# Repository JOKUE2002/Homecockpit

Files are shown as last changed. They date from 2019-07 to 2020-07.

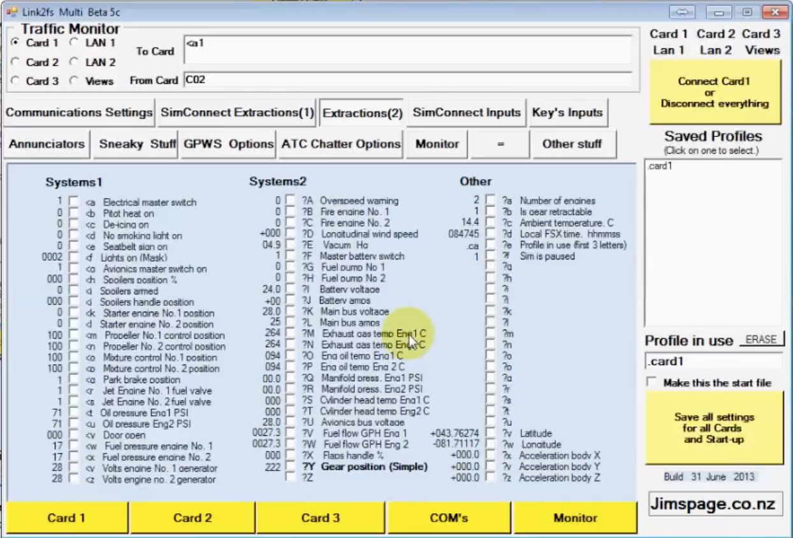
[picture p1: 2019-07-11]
hardware/simconnect-extractions2.png

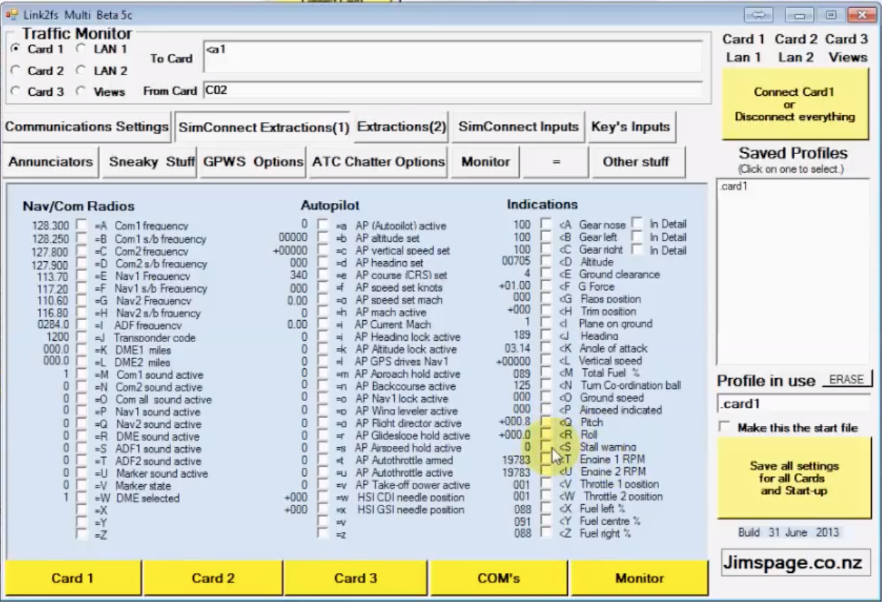
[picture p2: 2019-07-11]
hardware/simconnect-extractions1.png

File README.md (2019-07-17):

# Homecockpit

## What is it?
The homecockpit is a piece of hardware, that emulates a cockpit for a given computergame.
In this case we're emulating a "universal" cockpit in M$ FSX:SE.
"Universal" means, that it is adapted, so that it can be used on any aircraft type.

## What is the main concept?
The main concept is to have a big frame with cutouts, where panels are _slotted_. 
The frame features:
* space for 7 panels (6x 20x10cm + 1x 10x20cm), 
* a cutout for a monitor to show more complex instruments (PFD, GPS, ...)
* a cutout to fit the saitek yoke
* a powerbar
* an Arduino MEGA as the "brain"

## Which panels are already finished?
* Basic LightsPanel
  * bunch of simple two-state-switches to control lights in and around the aircraft
  * hardware nearly done ( First set of switches done, needs integration with Sim-commands panel)
  * software 0%
* Basic RadioPanel
  * 2 frequency displays + 1 knob (to set s/b freqency)
  * Hardware done (100%)
  * Software still WIP (w/ main firmare)
* AutopilotPanel Part 1
  * CRS, HDG, SPD displays + knobs
  * hardware done (100%)
  * software still WIP (w/ main firmare), but a beta has already been written and tested
* AutopilotPanel Part 2
  * ALT, V/S displays + knobs
  * hardware done (100%)
  * same software as AutopilotPanel Part 1
* Advanced RadioPanel
  * SQUAWK display + setting buttons; com/nav selector/switch buttons
  * hardware work in progress (50% done)
  * software not yet started, but easy (0%)
* Landing gear lever
  * lever with pull function to lock it into three positions (UP, LK, DN)
  * hardware WIP (lever done , installation + wiring missing)
  * software 0%
  
## Which panels are still planned?
* Sim-commands panel
  * buttons to command fsx (pause, slew mode, kneeboard, ...)
* Electrical panel
  * Hydraulics, APU, Generators, ...
* Engine Panel
  * Engine starters, fire suppresion, ...

## What's included?
In the "_pcb_" folder, there are the EAGLE **.sch**ematic/**.b**oa**rd** files for the custom PCBs we designed and ordered to make things easier.
In the "_firmware_" folder there are nearly all iterations of the firmaware, including the current version ("_FSX_3.0_").
In the "_parts_" folder there is a list of all the parts, that have been used to build the cockpit.

## How much is done is it?
If we had to guess this would be like one third done. There are still ~~a few~~ a lot of the planned panels missing. Also the main frame is still a work in progress.

### Individual statuses
* Frame: 70%
* Firmware: 40%
* Panels: 40%
* whole project: 30%

## Who's contributing?
Currently there are two main contributers:
Jonas (Hardware & Software specialist)
Cornelius (Flightsim/flying & design specialist)

## How can you contact us / help us?
Just create an issue. We'll answer on it as soon as possible.

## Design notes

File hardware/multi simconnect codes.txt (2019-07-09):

Send these codes from your Arduino with a 'Serial.println'
(The data burst needs to end with a linefeed)
There is nothing else for you to do. It will go to FSX automatically.
Some of these may not work on some planes. (Test them to check they work)

Simconnect direct injection codes.

Below are the codes you would send from the Arduino to do the required command.
You only need to send it once.
Make sure they are sent with "Serial.println(code)" command.
Note the println ,, as this sends the required linefeed after the code.

Examples ,,,
To raise the gear ,,,
Serial.println("C01");

To lower the gear ,,
Serial.println("C02");

To turn the autopilot on ,,
Serial.println("B03");

To set the transponder to 3254 ,,
Serial.println("A423254");

Make sure it's a capital letter.
This has nothing to do with the "Keys" section.
Just send the code from the Arduino and it will happen.
Easy, isn't it.?????

---- RADIO's  Codes --------------------------------------------------

A01	Decrements COM by one MHz
A02	Increments COM by one MHz
A03	Decrements COM by 25 KHz
A04	Increments COM by 25 KHz
A05xxxx	Sets COM frequency (In Hz) (A05 and 4 digits, the '1' is assumed, no dot)
A06	Swaps COM 1 frequency with standby
A07	Decrements COM2 by one MHz
A08	Increments COM2 by one MHz
A09	Decrements COM2 by 25 KHz
A10	Increments COM2 by 25 KHz
A11xxxx	Sets COM2 frequency(In Hz) (A11 and 4 digits, the '1' is assumed, no dot)
A12	Swaps COM 2 frequency with standby
A13	Decrements Nav 1 by one MHz
A14	Increments Nav 1 by one MHz
A15	Decrements Nav 1 by 25 KHz
A16	Increments Nav 1 by 25 KHz
A17xxxx	Sets NAV 1 frequency (In Hz) (A17 and 4 digits, the '1' is assumed, no dot)
A18	Swaps NAV 1 frequency with standby
A19	Decrements Nav 2 by one MHz
A20	Increments Nav 2 by one MHz
A21	Decrements Nav 2 by 25 KHz
A22	Increments Nav 2 by 25 KHz
A23xxxx	Sets NAV 2 frequency (In Hz) (A23 and 4 digits, the '1' is assumed, no dot)
A24	Swaps NAV 2 frequency with standby
A25	Increments ADF by 100 KHz
A26	Increments ADF by 10 KHz
A27	Increments ADF by 1 KHz
A28	Increments ADF 1 by 0.1 KHz.
A29	Decrements ADF by 100 KHz
A30	Decrements ADF by 10 KHz
A31	Decrements ADF by 1 KHz
A32	Decrements ADF 1 by 0.1 KHz.
A33xxxxx   Sets ADF 1 frequency (In Hz)  (A33 and 5 digits, no dot)
A34	Increments first digit of transponder
A35	Increments second digit of transponder
A36	Increments third digit of transponder
A37	Increments fourth digit of transponder
A38	Decrements first digit of transponder
A39	Decrements second digit of transponder
A40	Decrements third digit of transponder
A41	Decrements fourth digit of transponder
A42xxxx	Sets transponder code (A42 + 4 digits)
A43x	Sets the avionics master switch (0,1) A431 is on, A430 is off
A44	Toggles between NAV 1 and NAV 2
A45	Selects COM 1 to transmit
A46	Selects COM 2 to transmit
A47	Toggles all COM radios to receive on
A48	Toggles NAV 1 ID
A49	Toggles NAV 2 ID
A50	Toggles DME 1 ID
A51	Toggles DME 2 ID
A52	Toggles ADF 1 ID
A53	Toggles marker beacon sound on/off
A60x          DME select (A601 is DME1, A602 is DME2)

--- AUTOPILOT  Codes -----------------------------------------------------

A54	Toggles between GPS and NAV 1 driving NAV 1 OBS display (and AP)
A55	Decrements VOR 1's OBS setting (Course)
A56	Increments VOR 1's OBS setting  (Course)
A57	Increments heading hold reference bug
A58	Decrements heading hold reference
A59xxx	Set heading hold reference bug (degrees) (A59 and 1 to 3 digits)
B01	Toggles AP on/off
B02	Turns AP off
B03	Turns AP on
B04	Toggles heading hold mode
B05	Toggles altitude hold mode
B06	Toggles wing leveler mode
B07	Turns AP localizer hold on/armed and glide-slope hold mode off
B08	Toggle, Turns both AP localizer and glide-slope modes on/armed
B09	Toggles the backcourse mode for the localizer hold
B10	Toggles the nav hold mode
B11	Increments reference altitude
B12	Decrements reference altitude
B13	Increments vertical speed reference
B14	Decrements vertical speed reference
B15	Increments airspeed hold reference
B16	Decrements airspeed hold reference
B17	
B18	Increments reference mach
B19	Decrements reference mach
B20	Toggles mach hold
B21xxxx	Sets reference vertical speed in feet per minute (B21 & 3 or 4 digits)
B22xxx	Sets airspeed reference in knots (B22 and 1 to 3 digits)
B23xxx	Sets mach reference (B23 and 1 to 3 digits,  no dot)
B24	Turns airspeed hold on
B25	Turns airspeed hold off
B26           Toggle airspeed hold
B26x	Sets airspeed hold on/off (1,0)  (B261is on, B260 is off)
B27	Turns mach hold on
B28	Turns mach hold off
B29x	Sets mach hold on/off (1,0)  (B291is on, B290 is off)
B30	Toggles flight director on/off
B30x         Sets flight director on/off  (B301 is on, B300 is off)
B31	Toggle N1 hold
B32xxxxx  Sets altitude reference in feet  (B32 with 3 to 5 digits)
B33xxx      Sets OBS 1 (0 – 360)  (B32 with 1 to 3 digits)
B34           Toggle Autothrottle armed
B34x         Set autothrottle armed on/off  (B341 is on, B340 is off)
B35           Syncs altimeter setting to sea level pressure, or 29.92 if above 18000 feet 

--- OTHER  Codes------------------------------------------------------

C01	Sets gear handle in UP position
C02	Sets gear handle in DOWN
C03	Toggle gear handle
C04	Toggle parking brake on/off
C04x         Parking brake on/off (C041 is ON, C040 is off)
C05	Turns pitot heat switch on
C06	Turns pitot heat switch off
C07	Adds fuel to the aircraft, 25% of capacity at a time.
C08	Toggles pause on/off
C09	Turns on or off the fuel dump switch.
C10	Release one droppable object. Multiple key events will release multiple objects.
C11	Start up the auxiliary power unit (APU).(See E30)
C12	Extinguish all engine fires.
C13	Sets flap handle to full retract position
C14	Increments flap handle position
C15	Decrements flap handle position
C16	Sets flap handle to full extension position
C17xxx	Sets flap handle to closest increment (0 – 100%) (C17 with 1 to 3 digits)
C18	Increment elevator trim up
C19	Increments elevator trim down
C20	Sets auto-spoiler arming on
C21	Spoilers off
C22	Toggles spoiler handle
C23	Sets spoiler handle to full extend position
C24	Sets spoiler handle to full retract position
C25          Increase Kohlsman reading (Altimeter)
C26          Decrease Kohlsman reading (Altimeter)
C27          Increments rudder trim left
C28          Increments rudder trim right 
C29          Toggle "Push back" on/off
C30xxx    Cowl flap 1 set (0 – 100%) (C30 and 1 to 3 digits) 
C31xxx    Cowl flap 2 set (0 – 100%) (C30 and 1 to 3 digits) 
C32          Floats down (depends on plane if it works)
C33          Floats up (depends on plane if it works)
C34          Toggle smoke
C35          Smoke On
C36          Smoke Off
C37          Toggle wing folding
C38          Toggle tail hook handle
C39          Toggle water rudder

---  LIGHTS  Codes ---------------------------------------------

C41x       Nav lights   (C411 is On, C410 is Off)
C42x       Beacon lights   (C421 is On, C420 is Off)
C43x       Landing lights   (C431 is On, C430 is Off)
C44x       Taxi lights   (C441 is On, C440 is Off) 
C45x       Strobe lights   (C451 is On, C450 is Off)
C46x       Panel lights   (C461 is On, C460 is Off)
C47x       Recognition lights   (C471 is On, C470 is Off)
C48x       Wing lights   (C481 is On, C480 is Off) 
C49x       Logo lights   (C491 is On, C490 is Off) 
C50x       Cabin lights   (C501 is On, C500 is Off) 

---  ELECTRICAL  Codes  ----------------------------

A43x        Sets the avionics master switch (0,1) A431 is on, A430 is off
E01          Set engine 1 magnetos off 
E02          Toggle engine 1 right magneto
E03          Toggle engine 1 left magneto
E04          Set engine 1 magnetos on 
E05          Set engine 1 magnetos on and toggle starter
E06          Set engine 2 magnetos off
E07          Toggle engine 2 right magneto 
E08          Toggle engine 2 left magneto
E09          Set engine 2 magnetos on 
E10          Set engine 2 magnetos on and toggle starter 
E11          Set engine magnetos off
E12          Set engine right magnetos on
E13          Set engine left magnetos on 
E14          Set engine magnetos on 
E15          Set engine magnetos on and toggle starters (all)
E16          Toggle master battery switch
E17          Master battery switch OFF
E18          Master battery switch ON
E19          No.1  Alternator (generator) Toggle
E20          No.1  Alternator (generator) OFF
E21          No.1  Alternator (generator) ON
E22          No.2  Alternator (generator) Toggle
E23          No.2  Alternator (generator) OFF
E24          No.2  Alternator (generator) ON
E25          Toggle master alternator on/off
E26          Toggle master ignition switch  on/off
E27          Hydraulic pump switch 1    (E27 is toggle, E271 is On, E270 is Off)
E28          Hydraulic pump switch 2    (E28 is toggle, E281 is On, E280 is Off)
E29          Hydraulic pump switch 3    (E29 is toggle, E291 is On, E290 is Off)
C11         APU start 
E30          APU stop
E31          APU generator On
E32          APU generator Off
E33          Prop syncro switch   (E33 is toggle, E331 is on, E330 is off)
E34          Toggle all starters
E35          Triggers engine auto start
E36          Triggers engine auto shut down
E37          Triggers engine primer
E38          Toggle master ignitian switch
E39          Toggle master battery and alternator switch
E40          
E41          Toggle starter 1
E42          Starter 1  On
E43          Starter 1  Off
E44         Toggle starter 2
E45         Starter 2 On
E46         Starter 2 Off

--- FUEL  Systems  ---------------------------------------------

F01       Toggle fuels pumps on/off
F02x     Engine 1 fuel pump. (F021 is On, F020 is Off)
F03x     Engine 2 fuel pump. (F031 is On, F030 is Off)
F04x     Sets fuel selector 1 position (F04 and 1 or 2 digits ) (see list below)
F05x     Sets fuel selector 2 position (F05 and 1 or 2 digits ) (see list below)
		0 = Off
		1 = All
		2 = Left
		3 = Right
		4 = Left Aux
		5 = Right Aux
		6 = Center
		7 = Center2
		8 = Center3
		9 = External1
		10 = External2
		11 = Right tip
		12 = Left tip
		13 = Crossfeed
		14 = Crossfeed left to right
		15 = Crossfeed right to left
		16 = Both
		17 = External all
		18 = Isolate
F06        Crossfeed  On
F07        Crossfeed Off
F08        Add some fuel to total volume
F09        Turns on or off the fuel dump switch
F30        Toggle engine fuel valves
F31        Toggle engine 1 fuel valve
F32        Engine 1 fuel valve On
F33        Engine 1 fuel valve Off
F34        Toggle engine 2 fuel valve
F35        Engine 2 fuel valve On
F36        Engine 2 fuel valve Off

--- ANTI - ICE  Codes  --------------------------------------

F10        Anti ice On  
F11        Anti ice Off 
F12        Anti ice Toggle  
F13        Engine1 anti ice Off
F14        Engine1 anti ice On
F15        Engine2 anti ice Off
F16        Engine2 anti ice On
F17        Toggle structural de-ice
F18        Toggles propeller de-ice

---  HELICOPTERS  --------  Not tested, Maybe r22 only  ---------------

F19        Triggers rotor braking input
F20        Toggles on electric rotor clutch switch
F21        Sets electric rotor clutch switch On 
F22        Sets electric rotor clutch switch Off 
F23        Toggles the electric rotor governor switch
F24        Sets the electric rotor governor switch On
F25        Sets the electric rotor governor switch Off
F26        Increments the lateral (right) rotor trim
F27        Decrements the lateral (right) rotor trim

As mentioned above, some of these may not work on some planes.
Don't blame me ,, some planes are not set up 100% for simconnect ,,,
even M$ with the Baron ,, the de-ice wont work ,,
so TEST  THEM  FIRST before coding the Arduino for a particular planes function.

Also note ,,,
Some knobs or switches that appear to not work, actually may be working because 
the developer has not added the code to change the visual switch that you see.
Also if "X" wont work ,,, check that "Y" (and maybe "Z") is in the 'on' (or off) 
position first as some simconnect commands do away with the automatic 
'systems' stuff that happens for the casual user.

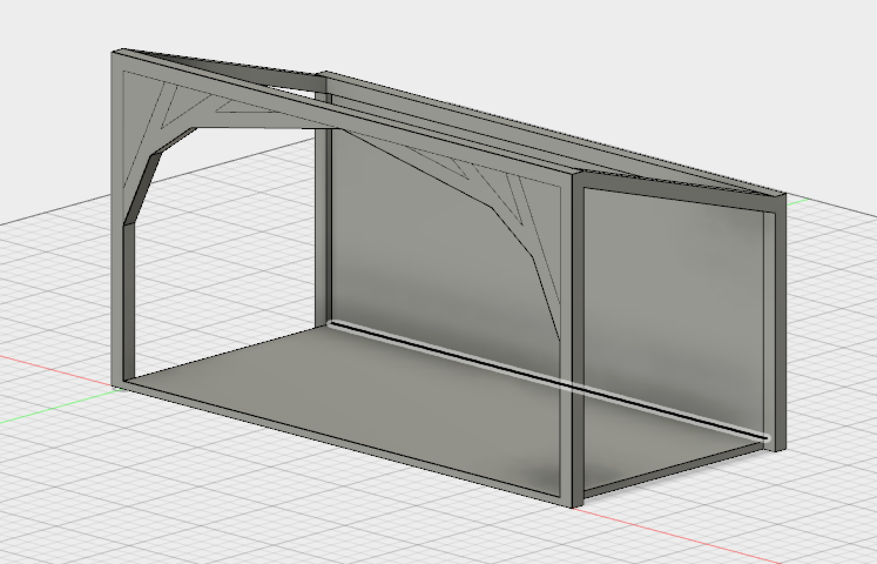
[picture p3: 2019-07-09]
hardware/Screenshot_1.png

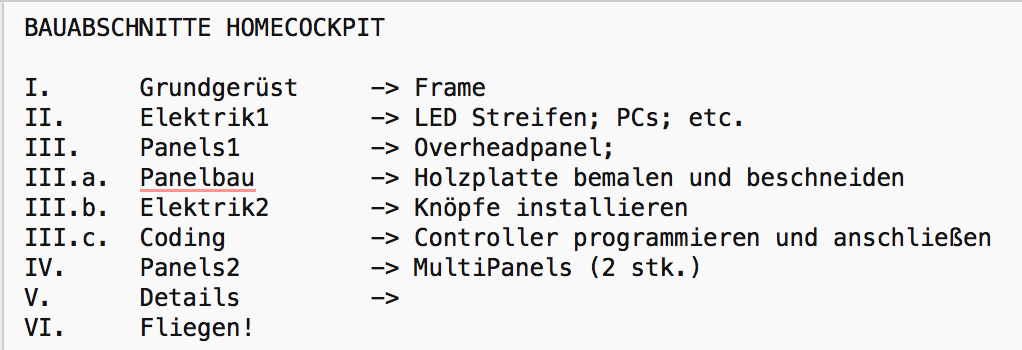
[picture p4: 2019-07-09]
hardware/Screenshot_4.png

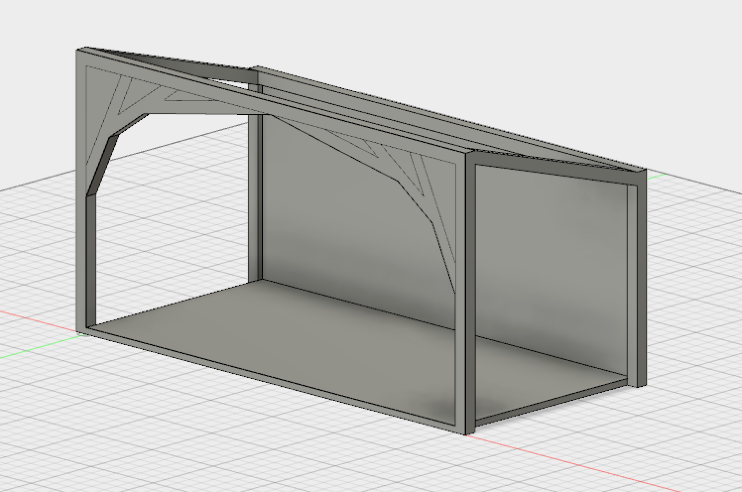
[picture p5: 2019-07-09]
hardware/Screenshot_2.png

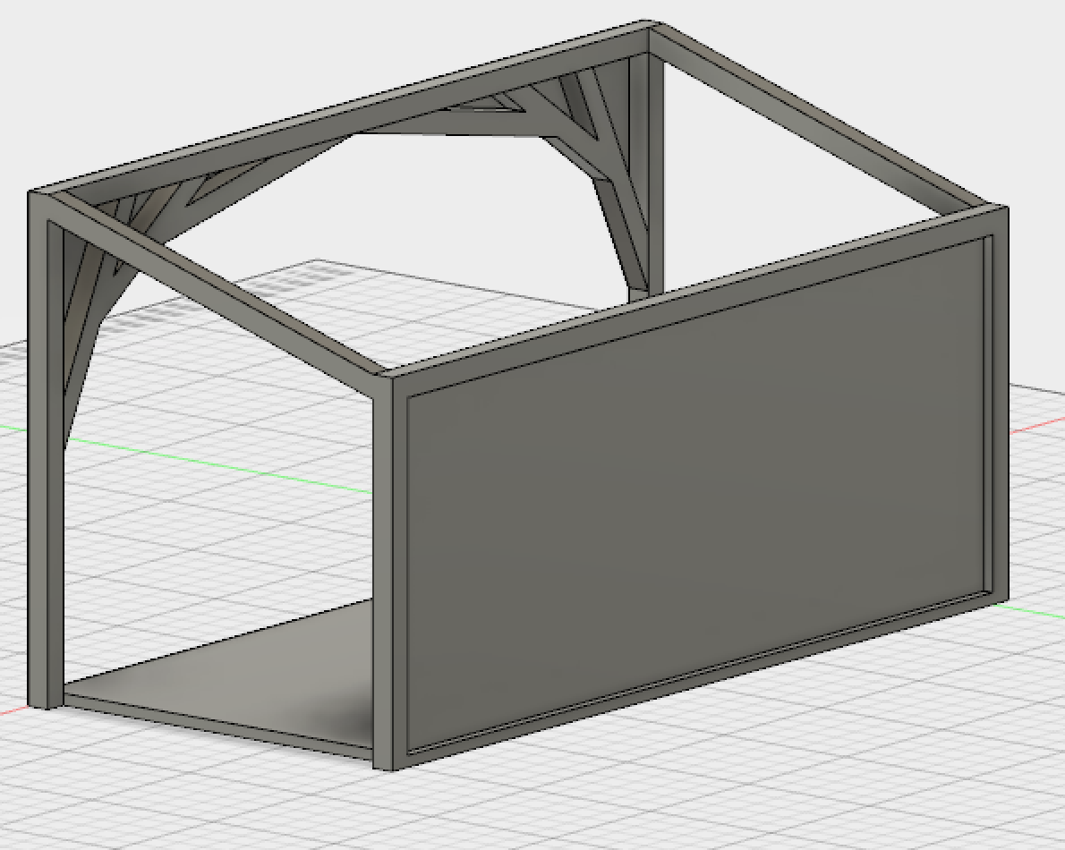
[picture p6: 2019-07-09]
hardware/Screenshot_3.png

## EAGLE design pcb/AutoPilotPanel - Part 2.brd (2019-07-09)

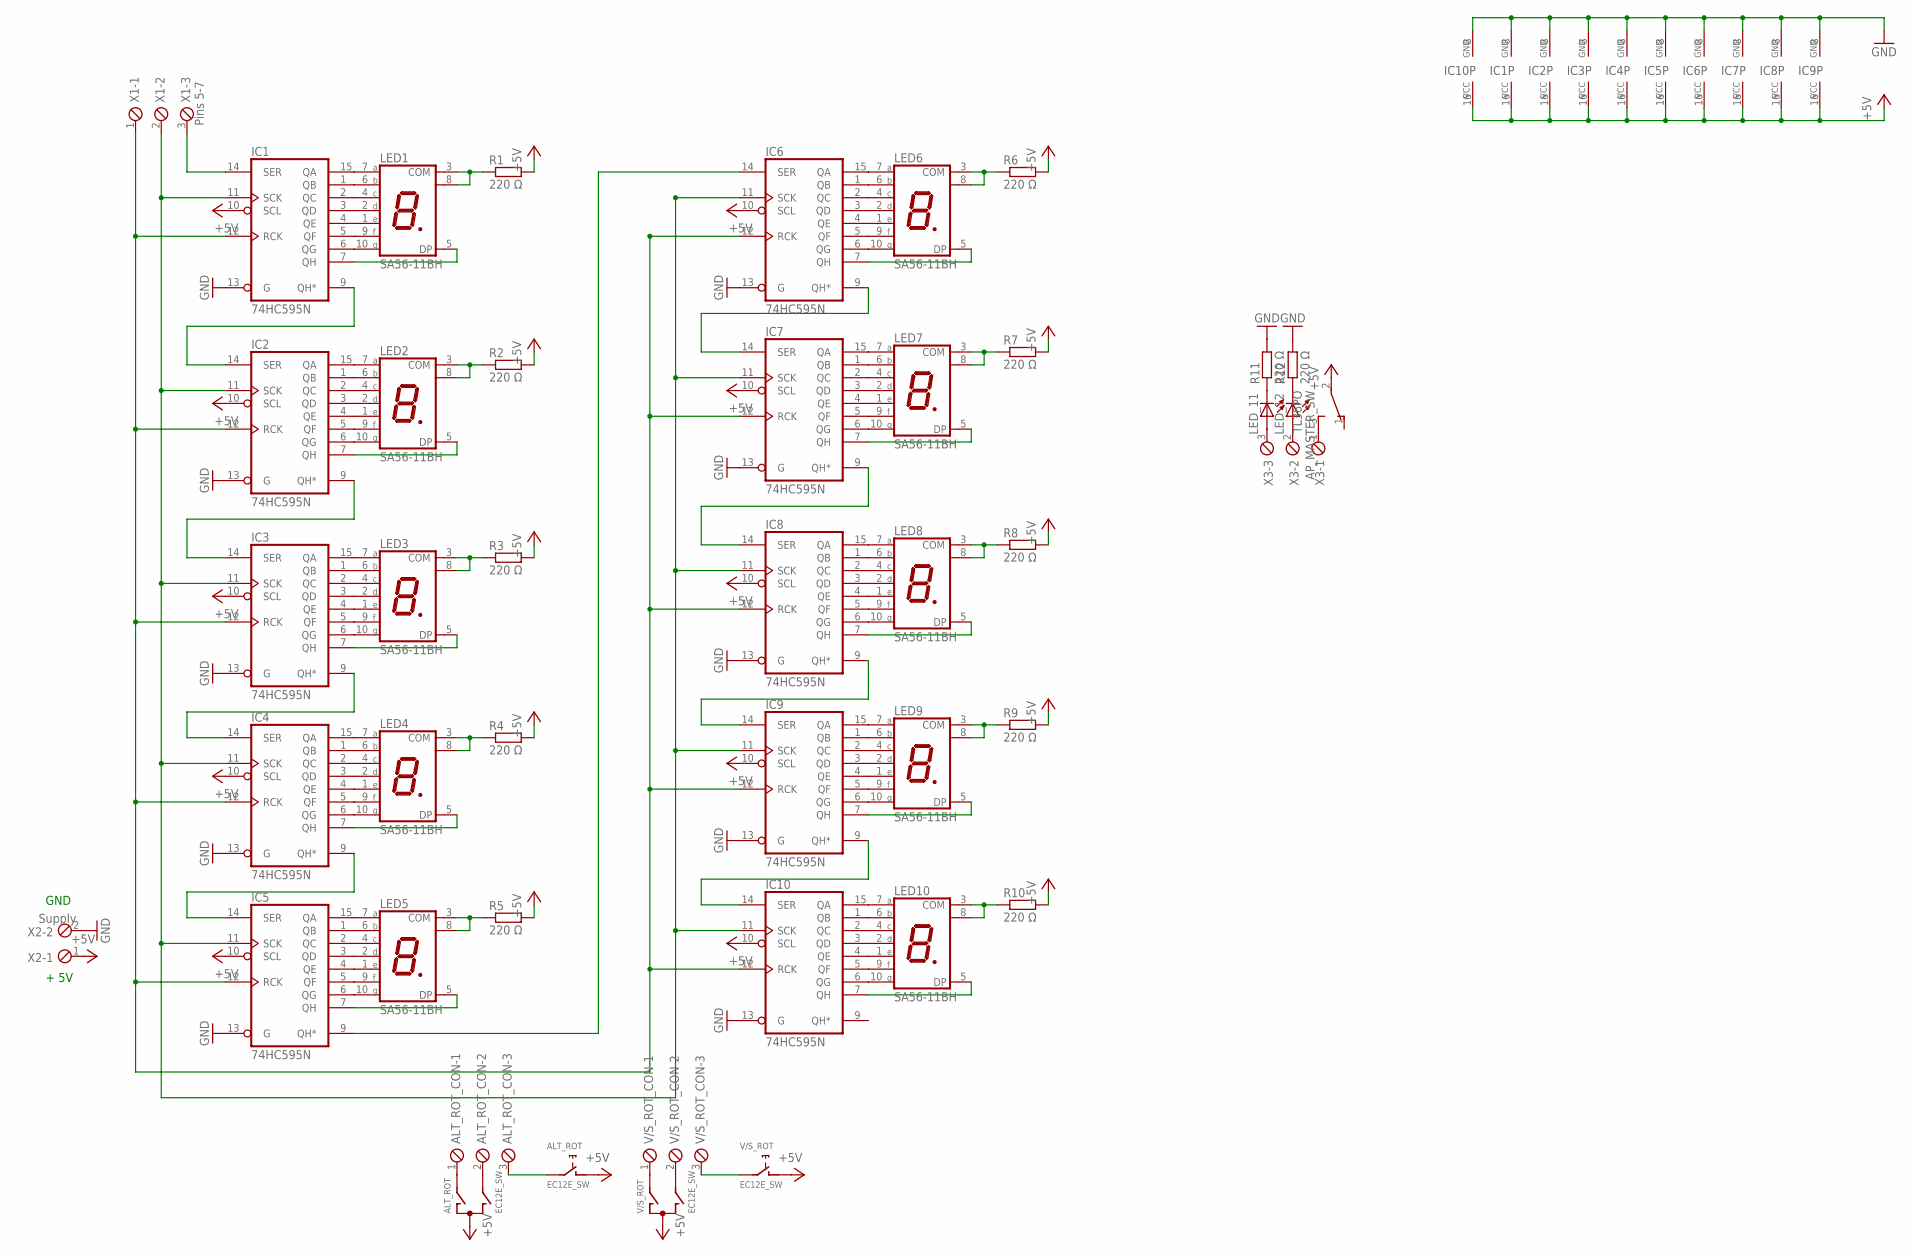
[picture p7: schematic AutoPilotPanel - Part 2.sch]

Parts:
ALT_ROT: EC12E_SW; ALPS_EC12E_SW
ALT_ROT_CON: MPT3; 3POL254
AP_MASTER_SW: TL36PO; TL3XPO
IC1, IC2, IC3, IC4, IC5, IC6, IC7, IC8, IC9, IC10: 74HC595N; DIL16
LED1, LED2, LED3, LED4, LED5, LED6, LED7, LED8, LED9, LED10: SA56-11BH; SA56-11
LED_11, LED_12: LED5MM
R1, R2, R3, R4, R5, R6, R7, R8, R9, R10, R11, R12: 220 Ω; 0207/12
V/S_ROT: EC12E_SW; ALPS_EC12E_SW
V/S_ROT_CON: MPT3; 3POL254
X1: Pins 5-7; 3POL254
X2: Supply; 2POL254
X3: MPT3; 3POL254

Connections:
+5V: ALT_ROT.C, ALT_ROT.D (1), AP_MASTER_SW.2, IC1.10 (SCL), IC1.16 (VCC), IC2.10 (SCL), IC2.16 (VCC), IC3.10 (SCL), IC3.16 (VCC), IC4.10 (SCL), IC4.16 (VCC), IC5.10 (SCL), IC5.16 (VCC), IC6.10 (SCL), IC6.16 (VCC), IC7.10 (SCL), IC7.16 (VCC), IC8.10 (SCL), IC8.16 (VCC), IC9.10 (SCL), IC9.16 (VCC), IC10.10 (SCL), IC10.16 (VCC), R1.2, R2.2, R3.2, R4.2, R5.2, R6.2, R7.2, R8.2, R9.2, R10.2, V/S_ROT.C, V/S_ROT.D (1), X2.1
GND: IC1.8 (GND), IC1.13 (G), IC2.8 (GND), IC2.13 (G), IC3.8 (GND), IC3.13 (G), IC4.8 (GND), IC4.13 (G), IC5.8 (GND), IC5.13 (G), IC6.8 (GND), IC6.13 (G), IC7.8 (GND), IC7.13 (G), IC8.8 (GND), IC8.13 (G), IC9.8 (GND), IC9.13 (G), IC10.8 (GND), IC10.13 (G), R11.2, R12.2, X2.2
unnamed: IC1.5 (QF), LED1.9 (F)
unnamed: IC1.3 (QD), LED1.2 (D)
unnamed: IC1.1 (QB), LED1.6 (B)
unnamed: IC1.15 (QA), LED1.7 (A)
unnamed: IC1.2 (QC), LED1.4 (C)
unnamed: IC1.4 (QE), LED1.1 (E)
unnamed: IC1.6 (QG), LED1.10 (G)
unnamed: IC2.5 (QF), LED2.9 (F)
unnamed: IC1.7 (QH), LED1.5 (DP)
unnamed: IC2.3 (QD), LED2.2 (D)
unnamed: IC2.1 (QB), LED2.6 (B)
unnamed: IC1.14 (SER), X1.3
unnamed: IC1.11 (SCK), IC2.11 (SCK), IC3.11 (SCK), IC4.11 (SCK), IC5.11 (SCK), IC6.11 (SCK), IC7.11 (SCK), IC8.11 (SCK), IC9.11 (SCK), IC10.11 (SCK), X1.2
unnamed: IC1.12 (RCK), IC2.12 (RCK), IC3.12 (RCK), IC4.12 (RCK), IC5.12 (RCK), IC6.12 (RCK), IC7.12 (RCK), IC8.12 (RCK), IC9.12 (RCK), IC10.12 (RCK), X1.1
unnamed: LED1.3 (COM), LED1.8 (COM), R1.1
unnamed: IC2.15 (QA), LED2.7 (A)
unnamed: IC2.2 (QC), LED2.4 (C)
unnamed: IC2.4 (QE), LED2.1 (E)
unnamed: IC2.6 (QG), LED2.10 (G)
unnamed: IC3.5 (QF), LED3.9 (F)
unnamed: IC3.3 (QD), LED3.2 (D)
unnamed: IC2.7 (QH), LED2.5 (DP)
unnamed: IC1.9 (QH*), IC2.14 (SER)
unnamed: IC3.1 (QB), LED3.6 (B)
unnamed: IC3.15 (QA), LED3.7 (A)
unnamed: LED2.3 (COM), LED2.8 (COM), R2.1
unnamed: IC3.2 (QC), LED3.4 (C)
unnamed: IC3.4 (QE), LED3.1 (E)
unnamed: IC3.6 (QG), LED3.10 (G)
unnamed: IC4.5 (QF), LED4.9 (F)
unnamed: IC4.3 (QD), LED4.2 (D)
unnamed: IC4.1 (QB), LED4.6 (B)
unnamed: IC4.15 (QA), LED4.7 (A)
unnamed: IC4.2 (QC), LED4.4 (C)
unnamed: IC4.4 (QE), LED4.1 (E)
unnamed: IC4.6 (QG), LED4.10 (G)
unnamed: IC5.5 (QF), LED5.9 (F)
unnamed: IC5.3 (QD), LED5.2 (D)
unnamed: IC5.1 (QB), LED5.6 (B)
unnamed: IC5.15 (QA), LED5.7 (A)
unnamed: IC5.2 (QC), LED5.4 (C)
unnamed: IC3.7 (QH), LED3.5 (DP)
unnamed: IC2.9 (QH*), IC3.14 (SER)
unnamed: IC5.4 (QE), LED5.1 (E)
unnamed: IC5.6 (QG), LED5.10 (G)
unnamed: LED3.3 (COM), LED3.8 (COM), R3.1
unnamed: IC6.5 (QF), LED6.9 (F)
unnamed: IC6.3 (QD), LED6.2 (D)
unnamed: IC6.1 (QB), LED6.6 (B)
unnamed: IC6.15 (QA), LED6.7 (A)
unnamed: IC6.2 (QC), LED6.4 (C)
unnamed: IC6.4 (QE), LED6.1 (E)
unnamed: IC6.6 (QG), LED6.10 (G)
unnamed: IC7.5 (QF), LED7.9 (F)
unnamed: IC7.3 (QD), LED7.2 (D)
unnamed: IC7.1 (QB), LED7.6 (B)
unnamed: IC7.15 (QA), LED7.7 (A)
unnamed: IC7.2 (QC), LED7.4 (C)
unnamed: IC7.4 (QE), LED7.1 (E)
unnamed: IC7.6 (QG), LED7.10 (G)
unnamed: IC8.5 (QF), LED8.9 (F)
unnamed: IC4.7 (QH), LED4.5 (DP)
unnamed: IC3.9 (QH*), IC4.14 (SER)
unnamed: IC8.3 (QD), LED8.2 (D)
unnamed: IC8.1 (QB), LED8.6 (B)
unnamed: LED4.3 (COM), LED4.8 (COM), R4.1
unnamed: IC8.15 (QA), LED8.7 (A)
unnamed: IC8.2 (QC), LED8.4 (C)
unnamed: IC8.4 (QE), LED8.1 (E)
unnamed: IC8.6 (QG), LED8.10 (G)
unnamed: IC9.5 (QF), LED9.9 (F)
unnamed: IC9.3 (QD), LED9.2 (D)
unnamed: IC9.1 (QB), LED9.6 (B)
unnamed: IC9.15 (QA), LED9.7 (A)
unnamed: IC9.2 (QC), LED9.4 (C)
unnamed: IC9.4 (QE), LED9.1 (E)
unnamed: IC9.6 (QG), LED9.10 (G)
unnamed: AP_MASTER_SW.3 (S), X3.1
unnamed: LED_12.A, X3.2
unnamed: LED_11.A, X3.3
unnamed: LED_11.K (C), R11.1
unnamed: IC5.7 (QH), LED5.5 (DP)
unnamed: IC4.9 (QH*), IC5.14 (SER)
unnamed: LED_12.K (C), R12.1
unnamed: LED5.3 (COM), LED5.8 (COM), R5.1
unnamed: ALT_ROT.A, ALT_ROT_CON.1
unnamed: ALT_ROT.B, ALT_ROT_CON.2
unnamed: ALT_ROT.E (2), ALT_ROT_CON.3
unnamed: IC10.7 (QH), LED10.5 (DP)
unnamed: IC9.9 (QH*), IC10.14 (SER)
unnamed: LED10.3 (COM), LED10.8 (COM), R10.1
unnamed: IC10.5 (QF), LED10.9 (F)
unnamed: IC10.3 (QD), LED10.2 (D)
unnamed: IC10.1 (QB), LED10.6 (B)
unnamed: IC10.15 (QA), LED10.7 (A)
unnamed: IC10.2 (QC), LED10.4 (C)
unnamed: IC10.4 (QE), LED10.1 (E)
unnamed: IC6.7 (QH), LED6.5 (DP)
unnamed: IC5.9 (QH*), IC6.14 (SER)
unnamed: IC10.6 (QG), LED10.10 (G)
unnamed: LED6.3 (COM), LED6.8 (COM), R6.1
unnamed: V/S_ROT.A, V/S_ROT_CON.1
unnamed: V/S_ROT.B, V/S_ROT_CON.2
unnamed: IC7.7 (QH), LED7.5 (DP)
unnamed: IC6.9 (QH*), IC7.14 (SER)
unnamed: LED7.3 (COM), LED7.8 (COM), R7.1
unnamed: IC8.7 (QH), LED8.5 (DP)
unnamed: IC7.9 (QH*), IC8.14 (SER)
unnamed: LED8.3 (COM), LED8.8 (COM), R8.1
unnamed: IC9.7 (QH), LED9.5 (DP)
unnamed: IC8.9 (QH*), IC9.14 (SER)
unnamed: LED9.3 (COM), LED9.8 (COM), R9.1
unnamed: V/S_ROT.E (2), V/S_ROT_CON.3

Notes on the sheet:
+ 5V
GND

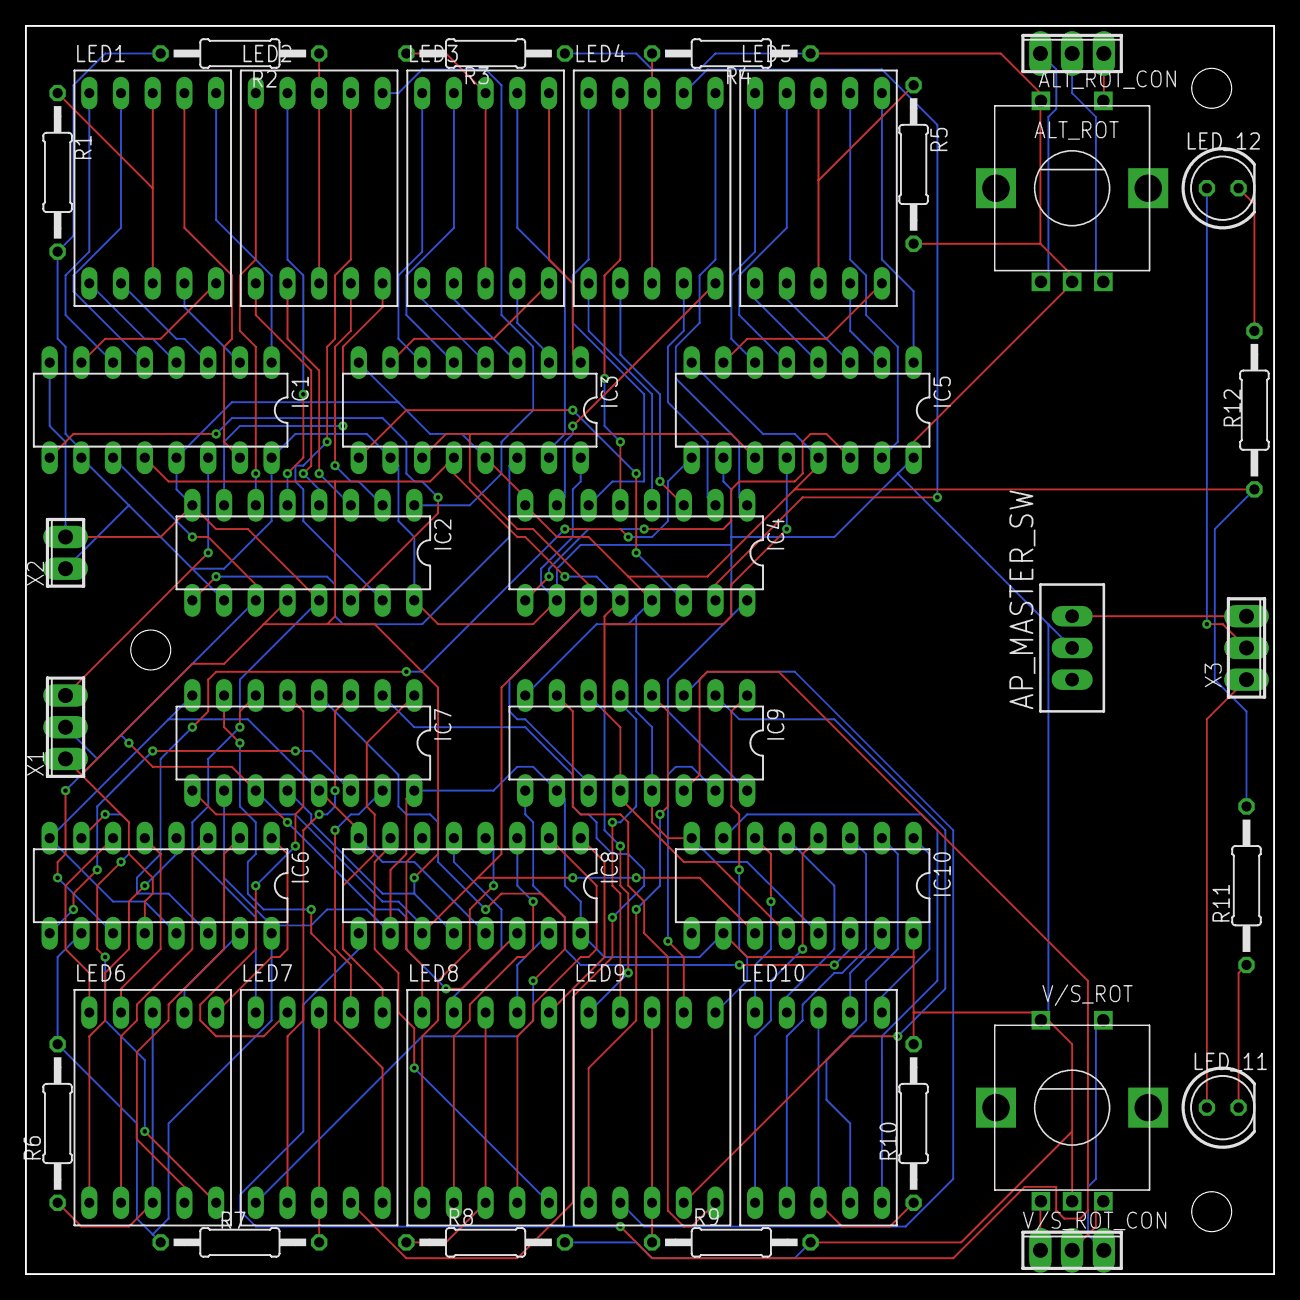
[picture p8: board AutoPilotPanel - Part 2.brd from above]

Board: 2 copper layers, 100.0 x 100.0 mm, 42 parts (0 on the bottom side), 115 nets.

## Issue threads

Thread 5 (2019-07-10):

Reinforce frame

JOKUE2002, 2019-07-10:
Currently the frame is weak and needs more strength from the back

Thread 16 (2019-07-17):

Middle console

Dachgruber, 2019-07-17:
A addition of a simple middle console could solve some issues related to the throttle and storage space for maps and documents. Could be something to work on after finishing everything else.

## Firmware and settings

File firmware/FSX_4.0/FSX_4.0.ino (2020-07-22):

/**
 * FSX MULTIPANEL FIRMWARE v4
 * (c) 2012 JOKUE2002 aka Jonas Kuehn
 * 
 * This panel can handle the autopilot and the radios of a 737 in FSX.
 * It's currently NOT using any extrenal library but some programs.
 * 
 * 
 * LIBRARIES AND EXTRENAL PROGRAMS NEEDED(*) +NICE TO HAVES(+)
 *  + Rotary Encoder Library - https://github.com/buxtronix/arduino
 *  * Link2FS                - http://www.jimspage.co.nz/link2fs_multi_fsx_v5h.zip
 *  + LiquidCrystal          - Standard Arduino Library 
 *                                (preinstalled with Arduino Software)
 *  * Arduino Software       - https://www.arduino.cc/en/Main/Software
 *  * FSUIPC                 - Preinstalled on FSX; 
 *                                You have to install it later, 
 *                                if you want to use FSX:SteamEdition
 *  * FSX / FSX:SE           - http://store.steampowered.com/app/314160/
 *  
 * INSTALLATION
 *  0.  Download all necessary files/installers.
 *  1.  Install Arduino and all its drivers.
 *  2.  Restart the Computer.
 *  3.  Install 
 *     a.  FSX 
 *     b.  Steam and FSX:SteamEdition
 *  4.  Copy the Rotary Encoder Library to the "Arduino/libraries/" folder, 
 *        which can be found in your "Documents" folder.
 *  5.  If you use FSX:SteamEdition, than you have to install FSUIPC. Therefor,
 *       go to: "C:\Program Files (x86)\Steam\steamapps\common\FSX\SDK\
 *        Core Utilities Kit\SimConnect SDK\LegacyInterfaces\FSX-RTM\"
 *       and double click on "SimConnect.msi" 
 *       (if there are multiple, just do all of them)
 *  6.  Now "install" Link2FS. You basically just have to download it and copy it 
 *       into a folder, that you won't "lose" or delete by accident. 
 *  7.  Upload this code to your Arduino MEGA 2560, with the hardware all built.
 *  8.  Start Link2FS and select all extractions in the list below at the 
 *      "Extractions(1)" and "Extractions(2)" tab.
 *  9.  Start FSX or FSX:SteamEdition. Go to freeflight, select your airport,
 *        and the 737 as the plane. Now start the flight.
 *  10. Start the card with the correct COM-Port after you connected the arduino 
 *      to your computer. 
 *  11. Enjoy the flight and your FSXPanel.
 *  
 * EXTRACTIONS THAT NEED TO BE ACTIVE
 *  =a AP(Autopilot)active
 *  =b AP altitude set
 *  =c AP vertical speed set
 *  =d AP heading set
 *  =e AP course (CRS) set
 *  =f AP speed set knots
 *  
 * PARTS NEEDED
 *  01x Arduino MEGA 2560
 *  19x 7Segment Displays
 *  19x 74ls595 or 74hc595 ICs
 *  01x AP1 PCB (found at the github repository)
 *  01x AP2 PCB (found at the github repository)
 *  06x LED 5mm
 *  21x 220Ohm resisitor (THT)
 * 
 * WIRING
 *  Solder the parts to the pcbs
 *  connect pin 1 (3 pin connector at bottom-left corner (seen from top); ap1)
 *    to pin 2 (on the arduino)
 *  connect pin 2 (same connector) to pin 3 (arduino)
 *  connect pin 3 (same connector) to pin 4 (arduino)
 *  
 *  connect pin 1 (3 pin connector at middle-left side (seen from top); ap2)
 *    to pin 5 (on the arduino)
 *  connect pin 6 (same connector) to pin 3 (arduino)
 *  connect pin 7 (same connector) to pin 4 (arduino)
 *  
 * RUNNING / USING
 *  1. Start FSX (as usual) and start into a flight. 
 *      Now pause the game (press "P")
 *  2. Start Link2FS (from your "link2fs" folder)
 *  3. Connect arduino to USB
 *  4. Connect arduino to link2s 
 *    (click connect on page 1 of link2fs and select com port of arduino)
 *  5. Resume FSX Game (Tab to FSX and press "P" again)
 *  
 */

/**
 * Pinout definition
 */

#define AP1DATA 22
#define AP1CLK 23
#define AP1LATCH 24

#define AP2DATA 25
#define AP2CLK 26
#define AP2LATCH 27


#define COM1DATA 28
#define COM1CLK 29
#define COM1LATCH 30

#define COM2DATA 31
#define COM2CLK 32
#define COM2LATCH 33


#define NAV1DATA 34
#define NAV1CLK 35
#define NAV1LATCH 36

#define NAV2DATA 37
#define NAV2CLK 38
#define NAV2LATCH 39

/**
 * Definition of data w/o dot on
 * Data: "0", "1", "2", "3", "4", "5", "6", "7", "8", "9", "-"
 */
byte dataArray[11] = 
{B00111111,
B00000110,
B01011011,
B01001111,
B01100110,
B01101101,
B01111101,
B00000111,
B01111111,
B01101111,
B01000000
};

byte dotOn = B10000000;

/**
 * all the data, which gets passed by Link2FS
 */
String hdg;
String crs;
String spd;
String alt;
String vs;
String c1a;
String c1s;
String c2a;
String c2s;
String n1a;
String n1s;
String n2a;
String n2s;

String oldhdg;
String oldcrs;
String oldspd;
String oldalt;
String oldvs;
String oldc1a;
String oldc1s;
String oldc2a;
String oldc2s;
String oldn1a;
String oldn1s;
String oldn2a;
String oldn2s;

enum callsForUpdate {
  HDG,
  SPD,
  ALT,
  CRS,
  VS,
  C1A,
  C1S,
  C2A,
  C2S,
  N1A,
  N1S,
  N2A,
  N2S
};


/**
 * MAIN SETUP
 * 1. Begin serial transmission
 * 2. define pin-outputs
 */
void setup() {
  Serial.begin(115200);
  
  pinMode(AP1DATA,OUTPUT);
  pinMode(AP1CLK,OUTPUT);
  pinMode(AP1LATCH,OUTPUT);
  digitalWrite(AP1LATCH, HIGH);
  digitalWrite(AP1DATA, LOW);
  digitalWrite(AP1CLK, LOW);

  pinMode(AP2DATA,OUTPUT);
  pinMode(AP2CLK,OUTPUT);
  pinMode(AP2LATCH,OUTPUT);
  digitalWrite(AP2LATCH, HIGH);
  digitalWrite(AP2DATA, LOW);
  digitalWrite(AP2CLK, LOW);

  clearData();
}

/**
 * MAIN LOOP
 * 
 * 1. clear all data
 * 2. check for serial signal
 * 3. decode signal (2-char-code, e.g. "=b")
 * 4. read and save data
 * 5. update displays
 */
void loop() {
  if(Serial.available()){
    
    char charIn = getChar();
    
    if(charIn == '='){
      
      charIn = getChar();
      
      if(charIn == 'd'){//HDG
        hdg = "";
        hdg += getChar();
        hdg += getChar();
        hdg += getChar();

        if(hdg != oldhdg) {
          updateDisplays(HDG);
          oldhdg = hdg;
        }
      }
      
      if(charIn == 'e'){//CRS
        crs = "";
        crs += getChar();
        crs += getChar();
        crs += getChar();

        if(crs != oldcrs) {
          updateDisplays(CRS);
          oldcrs = crs;
        }
      }
      
      if(charIn == 'f'){//SPD
        spd = "";
        spd += getChar();
        spd += getChar();
        spd += getChar();

        if(spd != oldspd) {
          updateDisplays(SPD);
          oldspd = spd;
        }
      }

      if(charIn == 'b'){//ALT
        alt = "";
        alt += getChar();
        alt += getChar();
        alt += getChar();
        alt += getChar();
        alt += getChar();

        if(alt != oldalt) {
          updateDisplays(ALT);
          oldalt = alt;
        }
      }

      if(charIn == 'c'){//VS
        vs = "";
        vs += getChar();
        vs += getChar();
        vs += getChar();
        vs += getChar();
        vs += getChar();
        vs += getChar();

        if(vs != oldvs) {
          updateDisplays(VS);
          oldvs = vs;
        }
      }

      if(charIn == 'A'){//Com1Active
        c1a = "";
        c1a += getChar();
        c1a += getChar();
        c1a += getChar();
        c1a += getChar();
        c1a += getChar();
        c1a += getChar();
        c1a += getChar();

        if(c1a != oldc1a) {
          updateDisplays(C1A);
          oldc1a = c1a;
        }
      }

      if(charIn == 'B'){//Com1Standby
        c1s = "";
        c1s += getChar();
        c1s += getChar();
        c1s += getChar();
        c1s += getChar();
        c1s += getChar();
        c1s += getChar();
        c1s += getChar();

        if(c1s != oldc1s) {
          updateDisplays(C1S);
          oldc1s = c1s;
        }
      }

      if(charIn == 'C'){//Com2Active
        c2a = "";
        c2a += getChar();
        c2a += getChar();
        c2a += getChar();
        c2a += getChar();
        c2a += getChar();
        c2a += getChar();
        c2a += getChar();

        if(c2a != oldc2a) {
          updateDisplays(C2A);
          oldc2a = c2a;
        }
      }

      if(charIn == 'D'){//Com2Standby
        c2s = "";
        c2s += getChar();
        c2s += getChar();
        c2s += getChar();
        c2s += getChar();
        c2s += getChar();
        c2s += getChar();
        c2s += getChar();

        if(c2s != oldc2s) {
          updateDisplays(C2S);
          oldc2s = c2s;
        }
      }

      if(charIn == 'E'){//Nav1Active
        n1a = "";
        n1a += getChar();
        n1a += getChar();
        n1a += getChar();
        n1a += getChar();
        n1a += getChar();
        n1a += getChar();

        if(n1a != oldn1a) {
          updateDisplays(N1A);
          oldn1a = n1a;
        }
      }

      if(charIn == 'F'){//Nav1Standby
        n1s = "";
        n1s += getChar();
        n1s += getChar();
        n1s += getChar();
        n1s += getChar();
        n1s += getChar();
        n1s += getChar();

        if(n1s != oldn1s) {
          updateDisplays(N1S);
          oldn1s = n1s;
        }
      }

      if(charIn == 'G'){//Nav2Active
        n2a = "";
        n2a += getChar();
        n2a += getChar();
        n2a += getChar();
        n2a += getChar();
        n2a += getChar();
        n2a += getChar();

        if(n2a != oldn2a) {
          updateDisplays(N2A);
          oldn2a = n2a;
        }
      }

      if(charIn == 'H'){//Nav2Standby
        n2s = "";
        n2s += getChar();
        n2s += getChar();
        n2s += getChar();
        n2s += getChar();
        n2s += getChar();
        n2s += getChar();

        if(n2s != oldn2s) {
          updateDisplays(N2S);
          oldn2s = n2s;
        }
      }
    }
  }
}

/**
 * Received the next char over the Serial-bus (USB)
 */
char getChar() {
  while(Serial.available() == 0);
  return((char)Serial.read());
}

/**
 * Receives a String of given length, using the getChar method
 */
String getString(int numOfChars){
  String tmp = "";
  for(int i = 0; i < numOfChars; i++){
    tmp += getChar();
  }
  return tmp;
}

/**
 * Translates received char into a byte to be displayed
 */
byte getDataForChar(char c) {
  switch(c){
  case '0': return dataArray[0]; break;
  case '1': return dataArray[1]; break;
  case '2': return dataArray[2]; break;
  case '3': return dataArray[3]; break;
  case '4': return dataArray[4]; break;
  case '5': return dataArray[5]; break;
  case '6': return dataArray[6]; break;
  case '7': return dataArray[7]; break;
  case '8': return dataArray[8]; break;
  case '9': return dataArray[9]; break;
  case '-': return dataArray[10]; break;
  default: return B00000000; break;
  }
}

/**
 * Calls all display update functions
 * 
 * The number indicates, which one called
 */
void updateDisplays(callsForUpdate caller) {
  if(caller == HDG || caller == SPD || caller == CRS) {
    updateAP1();
  }
  if(caller == ALT || caller == VS){
    updateAP2();
  }
  if(caller == C1A || caller == C1S){
    updateCom1();
  }
  if(caller == C2A || caller == C2S){
    updateCom2();
  }
  if(caller == N1A || caller == N1S){
    updateNav1();
  }
  if(caller == N2A || caller == N2S){
    updateNav2();
  }
 }

/**
 * Writes data from ap1data-array to display1
 */
void updateAP1() {
  String full = spd + hdg + crs;
  
  int len = full.length(); 
  char char_array[len];
  
  full.toCharArray(char_array, len);
  
  digitalWrite(AP1LATCH, LOW);
  delay(20);
  for(int i = len; i >= 0; i--){
    delay(2);
    shiftOut(AP1DATA, AP1CLK, MSBFIRST, ~getDataForChar(char_array[i]));
  }
  delay(20);
  digitalWrite(AP1LATCH, HIGH);
}

/**
 * Writes data from ap2data-array to display2
 */
void updateAP2() {
  /*digitalWrite(AP2LATCH, LOW);
  for(int i = 10; i >= 0; i--){
    delay(1);
    shiftOut(AP2DATA, AP2CLK, MSBFIRST, ~ap2data[i]);
  }
  digitalWrite(AP2LATCH, HIGH);*/
}

/**
 * Writes data from com1data- & com1sbdata-array to display3
 */
void updateCom1() {
  /*digitalWrite(COM1LATCH, LOW);
  for(int i = 10; i >= 0; i--){
    delay(1);
    shiftOut(COM1DATA, COM1CLK, MSBFIRST, ~com1data[i]);
  }
  digitalWrite(COM1LATCH, HIGH);*/
}

/**
 * Writes data from com2data- & com2sbdata-array to display4
 */
void updateCom2() {
  /*digitalWrite(COM2LATCH, LOW);
  for(int i = 4; i >= 0; i--){
    delay(1);
    shiftOut(COM2DATA, COM2CLK, MSBFIRST, ~com2data[i]);
  }
  digitalWrite(COM2LATCH, HIGH);*/
}

/**
 * Writes data from nav1data- & nav1sbdata-array to display5
 */
void updateNav1() {
  /*digitalWrite(NAV1LATCH, LOW);
  for(int i = 10; i >= 0; i--){
    delay(1);
    shiftOut(NAV1DATA, NAV1CLK, MSBFIRST, ~nav1data[i]);
  }
  digitalWrite(NAV1LATCH, HIGH);*/
}

/**
 * Writes data from nav2data- & nav2data-array to display6
 */
void updateNav2() {
  /*digitalWrite(NAV2LATCH, LOW);
  for(int i = 10; i >= 0; i--){
    delay(1);
    shiftOut(NAV2DATA, NAV2CLK, MSBFIRST, ~nav2data[i]);
  }
  digitalWrite(NAV2LATCH, HIGH);*/
}

/**
 * Clears data from all *data-arrays and all displays
 */
void clearData() {
  spd = "";
  oldspd = "a";
  hdg = "";
  oldhdg = "a";
  crs = "";
  oldcrs = "a";
  
  //Clear Ap1 display + data-array
  digitalWrite(AP1LATCH, LOW);
  delay(20);
  for(int i = 0; i < 9; i++){
    delay(2);
    shiftOut(AP1DATA, AP1CLK, MSBFIRST, ~B00000000);
  }
  delay(20);
  digitalWrite(AP1LATCH, HIGH);
}

void fillData() {
  digitalWrite(AP1LATCH, LOW);
  delay(20);
  for(int i = 0; i < 9; i++){
    delay(2);
    shiftOut(AP1DATA, AP1CLK, MSBFIRST, B00000000);
  }
  delay(20);
  digitalWrite(AP1LATCH, HIGH);
}

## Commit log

2019-07-09 Data upload
    Uploading a whole bunch of data from my pc
    [AutoPilotPanel - Part 1.brd, AutoPilotPanel - Part 1.sch, AutoPilotPanel - Part 2.brd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]
2019-07-09 Renamed files
    Files renamed + packaged the way arduino likes it
2020-07-22 Firmware v4
    In this update we changed the firmware design by adding delays to the displaysroutines spliting parts of the displaying (only the display with the changed bits gets an update). This also addresses the bugs caused by the byte-array-storage (we went back to Strings).
    Note: Only the AP1 module has been implemented (yet), due to unfinished designchoises regarding the decimal point in the com/nav modules.
    It also hasn't been tested (yet), but I'm up to it.
    [FSX_4.0.ino]
